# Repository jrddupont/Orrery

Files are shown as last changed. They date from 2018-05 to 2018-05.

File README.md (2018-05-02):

# Digital Orrery

This is a project to create a digital [orrery][orrery], each planet can be addressed and controlled individually.

## Parts list

* [4x Nema 17 stepper motors, 40mm][motors]
* An Arduino Uno
* [Arduino CNC shield][cnc]
* All of the 3D printed parts

## Current Functions

Currently the orrery has two functions, animate and date mode. In its default mode, the orrery slowly spins the four planets at realistic relative speeds meaning that Mars spins 8 times slower than Mercury. The accuracy of the animation is acceptable as it is within 4% of real speeds, although the method used creates unrealistic cycles that happen noticeably often.  
The second function is to snap to a position when given a date over serial. When given an input date, the number of days between the given date and 1/1/2000 is calculated. The actual positions of the planets at 1/1/2000 is known as well as how far the planets move in a day, so it is as simple as multiplying the day delta by the planet speed to find its new location. 

## Problems  

There are a number of problems with this device, namely that it slowly drifts out of alignment and becomes inaccurate. The source of this inaccuracy is from stepper motors missing steps, so a solution may be to increase power to the steppers or to measure where the planets are via a rotary encoder.   
In a similar vein, when the orrery is started it takes its current state as being zeroed out and will assume all the planets are aligned. This is undesired because it means that every single time it is started it needs to be realigned. This problem would also be fixed with rotary encoders. 

## Future Plans

Things I would like to add or fix:  
* Some way for the arduino to know where the planets are, either a rotary encoder or a bump that a switch can detect. 
* An LCD screen and buttons to allow user input without the need for a computer.
* An enclosure for the arduino and shield to make transportation easier, as well as improve aesthetics. 

## Demonstration

Whole device:  
Whole device  

Close up:  
Closer device

Video:  
Video (http://www.youtube.com/watch?v=tbyMe05wM1g "Orrery Working")

More info found [here][thingiverse]

[thingiverse]: https://www.thingiverse.com/thing:2889266
[motors]: https://www.amazon.com/gp/product/B00PNEQI7W
[cnc]: https://www.amazon.com/gp/product/B06XJKVLG3
[wide]: https://i.imgur.com/hOvwWhX.jpg 
[close]: https://i.imgur.com/2LTnKSo.jpg
[orrery]: https://en.wikipedia.org/wiki/Orrery

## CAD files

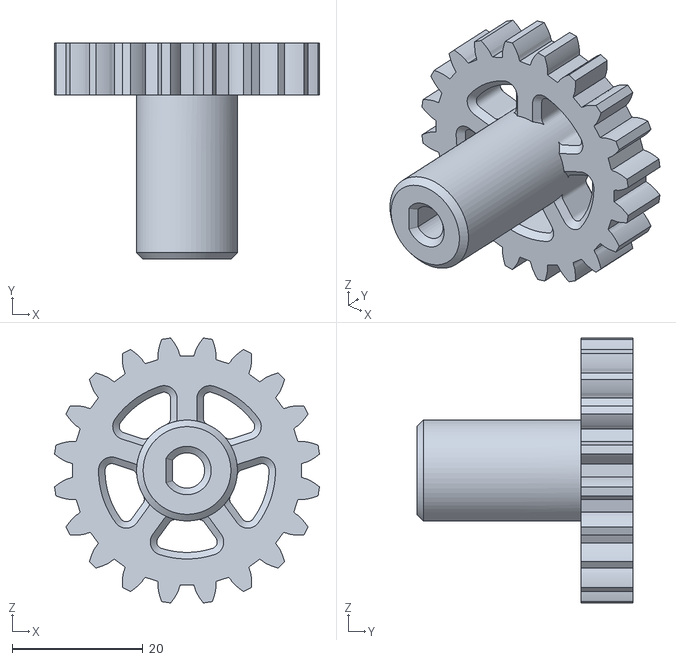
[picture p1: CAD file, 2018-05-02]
3D Parts/Drive 3.stl
40.5 x 33.1 x 40.5

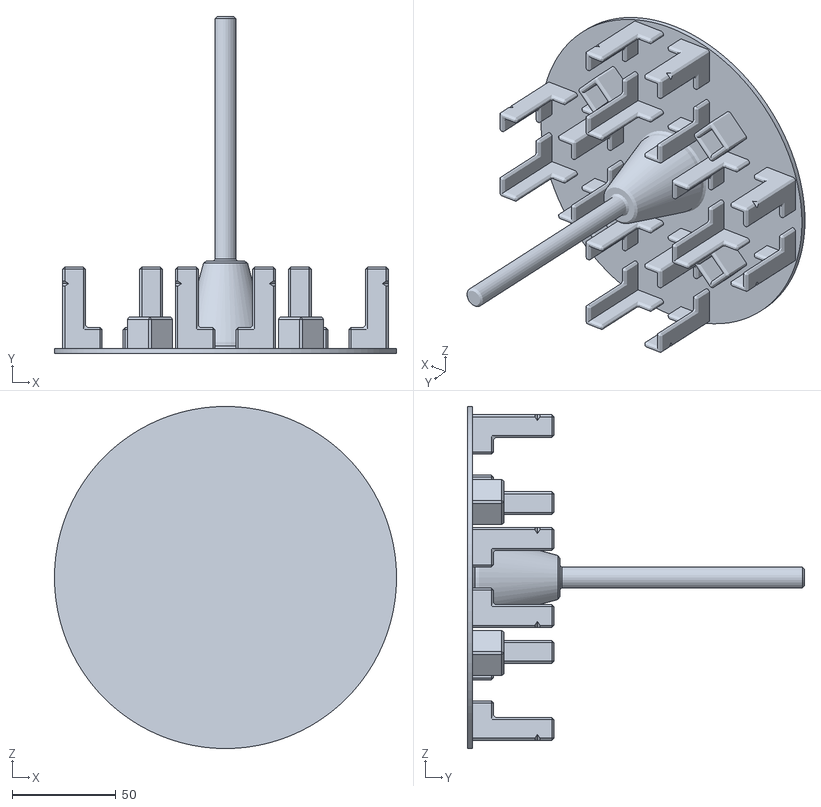
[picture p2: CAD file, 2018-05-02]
3D Parts/Base.stl
165.0 x 162.5 x 165.0

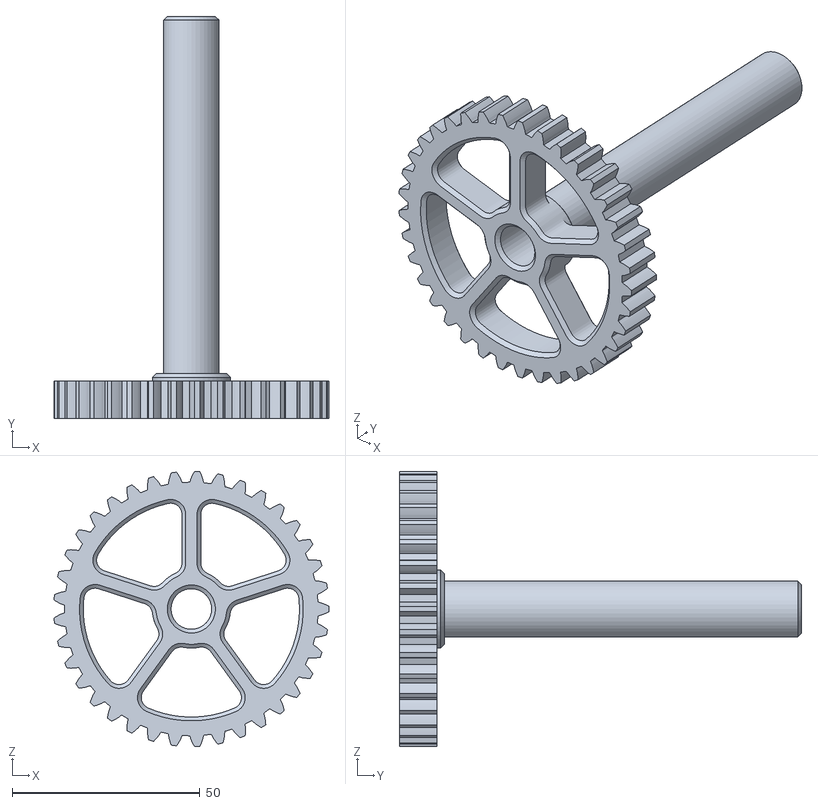
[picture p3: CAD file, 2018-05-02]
3D Parts/Shaft 1.stl
73.2 x 107.0 x 73.2

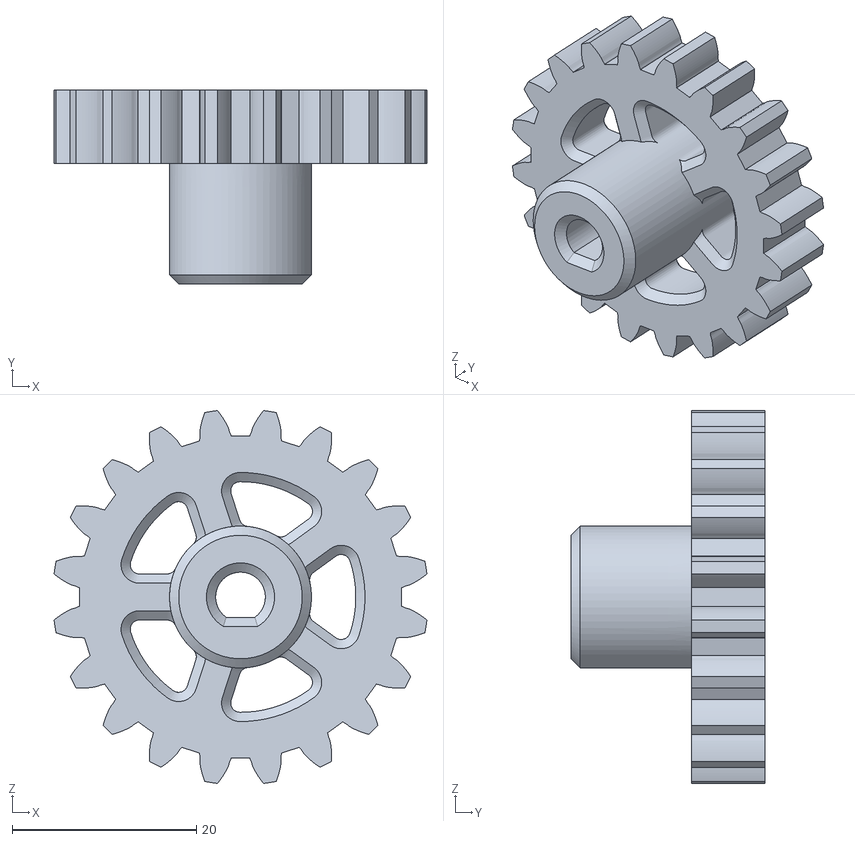
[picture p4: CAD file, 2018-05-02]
3D Parts/Drive 2.stl
40.5 x 21.1 x 40.5

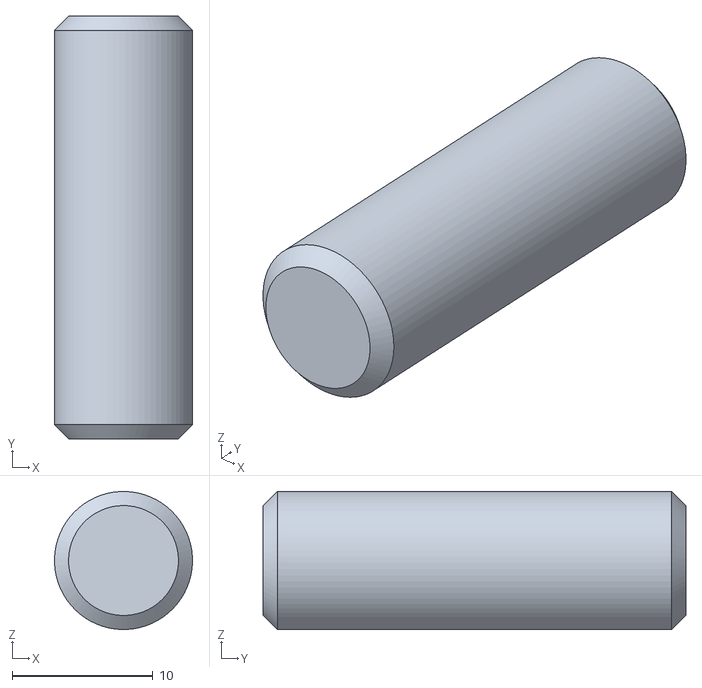
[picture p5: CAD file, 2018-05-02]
3D Parts/Sun Pin.stl
9.80 x 30.0 x 9.80

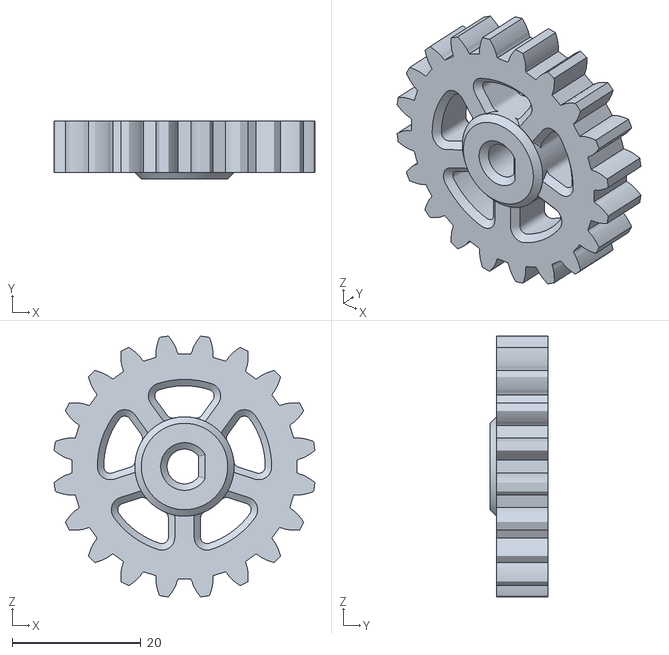
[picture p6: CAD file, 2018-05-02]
3D Parts/Drive 1.stl
40.5 x 9.05 x 40.5

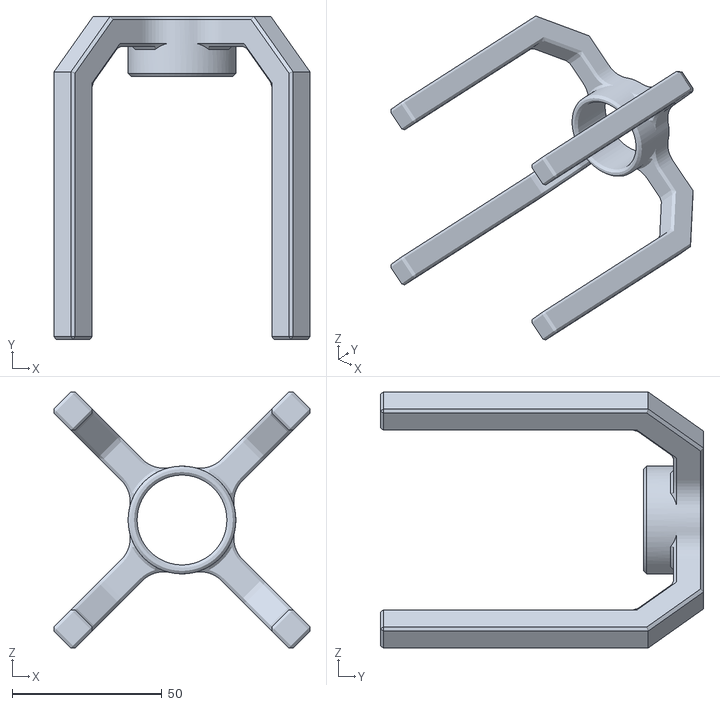
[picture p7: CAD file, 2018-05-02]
3D Parts/Support Strut.stl
85.6 x 108.0 x 85.6

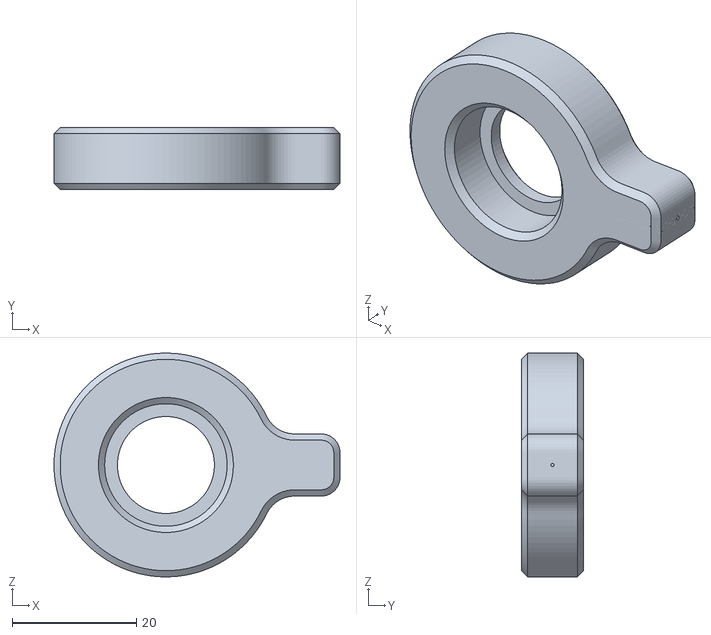
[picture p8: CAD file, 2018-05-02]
3D Parts/Collar 2.stl
46.0 x 10.0 x 36.0

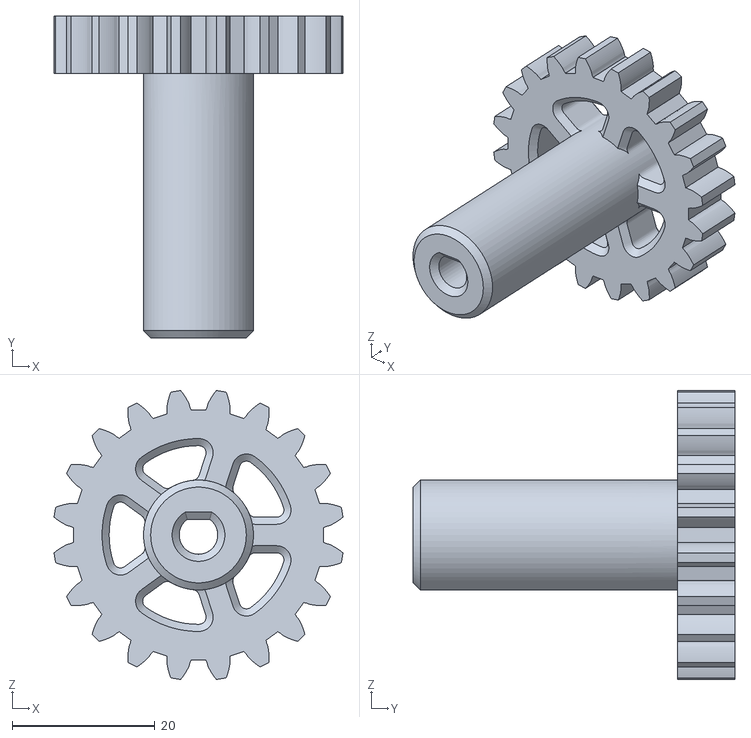
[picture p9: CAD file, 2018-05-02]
3D Parts/Drive 4.stl
40.5 x 45.1 x 40.5

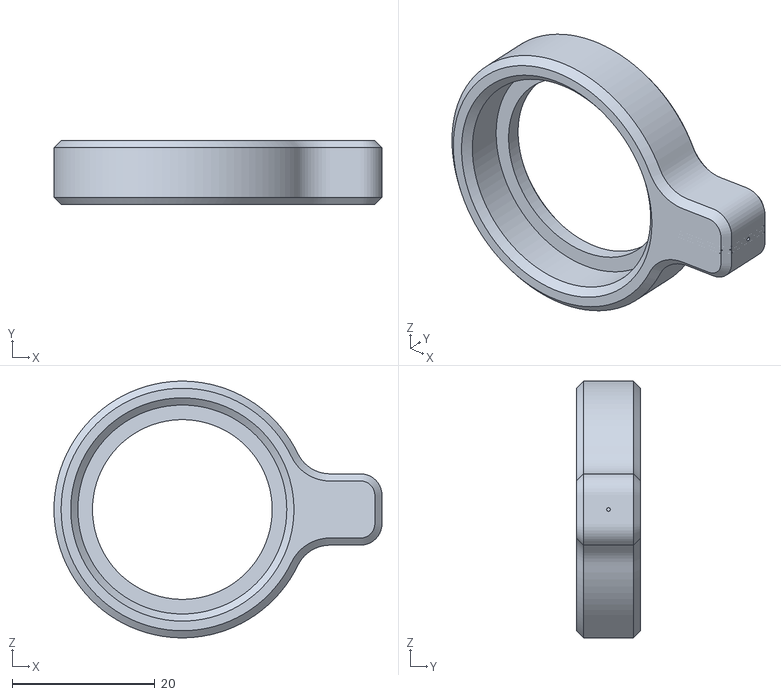
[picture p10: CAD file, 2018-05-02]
3D Parts/Collar 4.stl
46.0 x 9.00 x 36.0

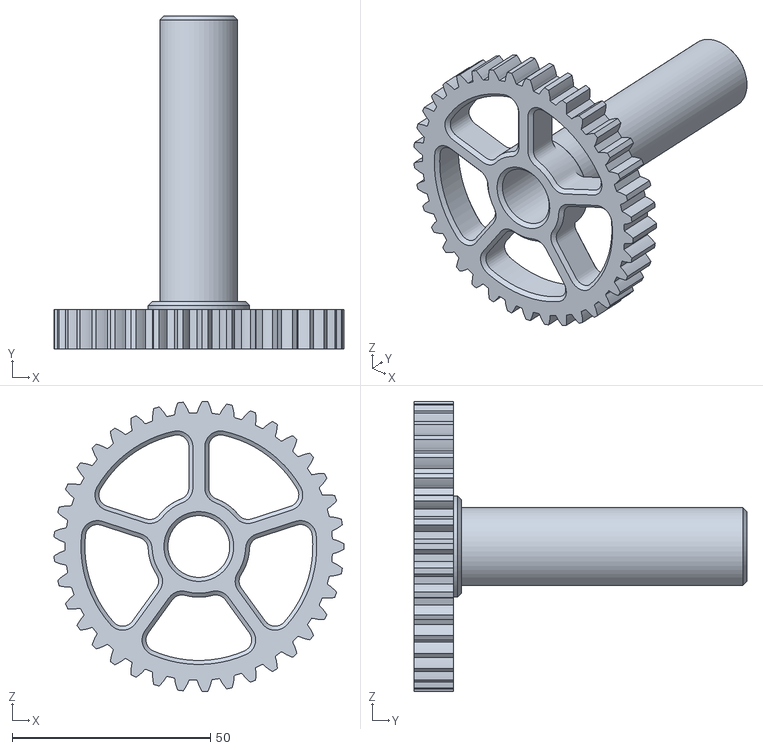
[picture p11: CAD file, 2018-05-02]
3D Parts/Shaft 2.stl
73.2 x 84.0 x 73.2

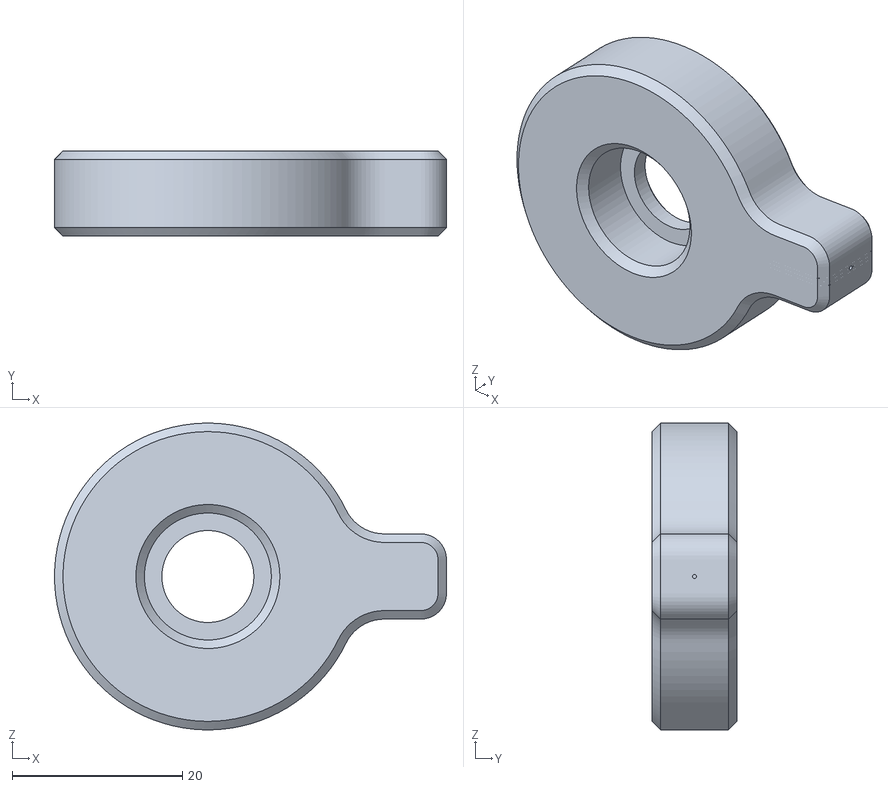
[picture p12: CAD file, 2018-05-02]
3D Parts/Collar 1.stl
46.0 x 10.0 x 36.0

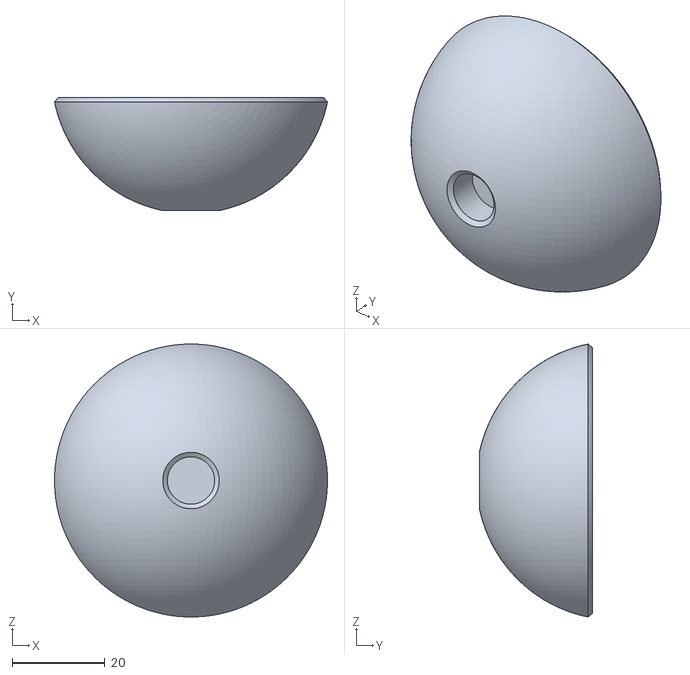
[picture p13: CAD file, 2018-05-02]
3D Parts/Sun Lower.stl
58.8 x 24.4 x 58.8

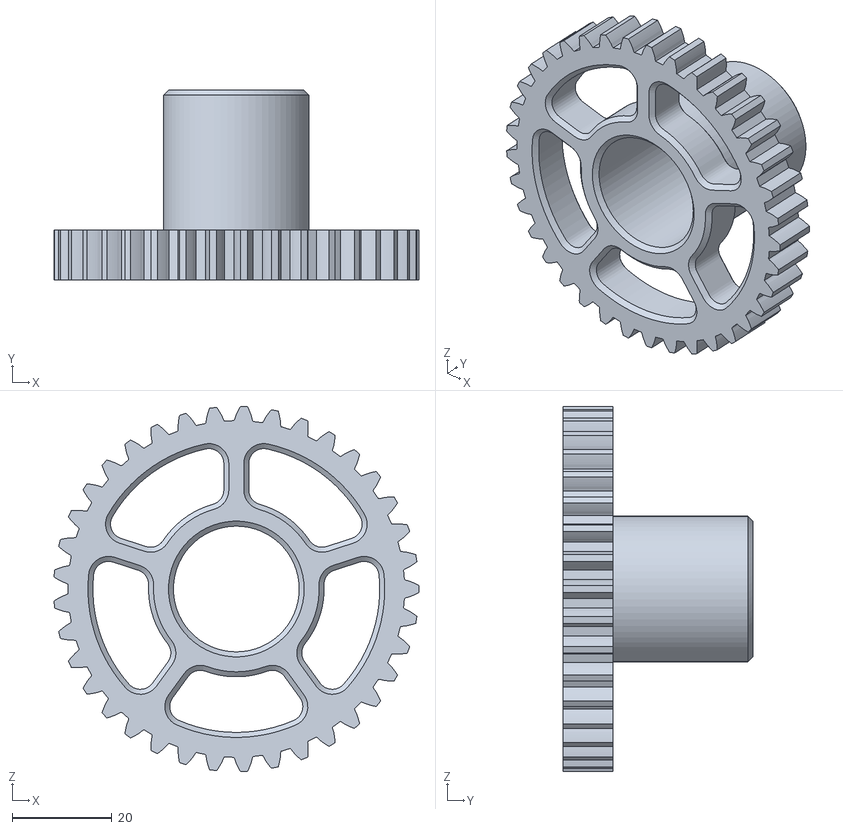
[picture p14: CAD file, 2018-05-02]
3D Parts/Shaft 4.stl
73.2 x 38.0 x 73.2

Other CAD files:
3D Parts/Collar 3.stl
3D Parts/Sun Upper.stl
3D Parts/Shaft 3.stl

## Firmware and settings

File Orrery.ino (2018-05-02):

#define MAX_STEP (2960)		// Number of steps per full planet revolution
#define STEP_DELAY (150)	// Time in uS to wait inbetween steps

#define CHECK_BIT(var,pos) ((var) & (1<<(pos)))	// Checks if bit `pos` in `var` is 1
#define TO_RADIAN(A) (PI * (A) / 180)	// Converts from degree to radian
#define TO_DEGREE(R) ((R) * (180/PI))	// Converts from radian to degree
#define POS_TO_STEP(P) (P * MAX_STEP)	// Converts a float from 0-1 to 0-MAX_STEP


#define ENABLE (8)	// Pin that enables or disables all motor control

// Direction pins
#define MRC_DIR	(5)
#define VNS_DIR	(6)
#define ERT_DIR	(13)
#define MRS_DIR	(7)

// Step pins
#define MRC_STP	(2)
#define VNS_STP	(3)
#define ERT_STP	(12)
#define MRS_STP	(4) 

// Enumerations for the planets, used primaraly as indexes for arrays
#define MERCURY (0)
#define VENUS (1)
#define EARTH (2)
#define MARS (3)

// Directions :D
#define LEFT (true)
#define RIGHT (!LEFT)

// Defines what mode to send to the arduino, currently only HYBRID exists. 
#define HYBRID

// A date has day 'd', month 'm' and year 'y'
struct Date {
	int d, m, y;
};

byte directionPins[4] = {MRC_DIR, VNS_DIR, ERT_DIR, MRS_DIR};
byte stepPins[4] = {MRC_STP, VNS_STP, ERT_STP, MRS_STP};

int stepPositions[4] = {0, 0, 0, 0};	// Current actual positons of the stepper motors, although this can become inaccurate over time with missed steps
float floatPositions[4] = {0, 0, 0, 0}; 	// Desired position to go to when stepToCurrentPosition() is called

// Variables for serial date input
Date inputDate = {.d = 0, .m = 0, .y = 0};
boolean inputComplete = false;  // whether the input is complete

void setup(){
	// Starts serial
	Serial.begin(9600);
	
	// Set all direction, step, and enable pins to output
	for(int i = 0; i < 4; i++){
		pinMode(directionPins[i], OUTPUT);
		pinMode(stepPins[i], OUTPUT);
	}
	pinMode(ENABLE, OUTPUT);

	// Setup animation
	initAnimation();
	
	// 5 second delay before starting animation to allow for manual alignment
	digitalWrite(ENABLE, HIGH);
	delay(5000);
	digitalWrite(ENABLE, LOW);
	delay(500);
}

void loop(){
	#ifdef HYBRID
		// If there is a date input
		if (inputComplete) {
  			Serial.println(inputDate.y);
  			Serial.println(inputDate.m);
  			Serial.println(inputDate.d);

  			// calculate input date's position and snap to it, then wait 5 seconds before animating again
  			setPositionByDate(inputDate);
  			stepToCurrentPosition();
  			delay(5000);
  			inputDate = {.d = 0, .m = 0, .y = 0};
  			inputComplete = false;
  			initAnimation();
		}
		animationStep();	// Just keep animating if there was no input
		delay(2);	// This can be adjusted to make it animate faster or slower
		//delayMicroseconds(1000);	// Minimum is probably like 250 
	#endif
}

// Patterns that all the planets step to while in an animation state, Mercury always steps and MARS steps 1/8 of the time, etc.
byte stepPatterns[4] = { B11111111, B10100100, B10001000, B10000000};
byte currentAnimationStep = 0; // Will always be 0-7

// Makes one animation step, DOES NOT delay at all, must delay outside of this function (calling this in a loop will cause the steppers to miss steps)
void animationStep(){

	// If the position of the current animation step has a 1, make the step
	for(int planet = 0; planet < 4; planet++){
		if(CHECK_BIT(stepPatterns[planet], currentAnimationStep)){
			stepPositions[planet] = (stepPositions[planet] + 1) % MAX_STEP;
			digitalWrite(stepPins[planet], HIGH);
		}
	}
	// Minimum amount of time for the step to successfully happen
	delayMicroseconds(STEP_DELAY);

	// Reset all pins to low
	for(int planet = 0; planet < 4; planet++){
		digitalWrite(stepPins[planet], LOW);
	}
	delayMicroseconds(STEP_DELAY);
	currentAnimationStep = (currentAnimationStep + 1) % 8;
}

// Must be called before attempting to animate
void initAnimation(){
	currentAnimationStep = 0;
	for(int planet = 0; planet < 4; planet++){
		digitalWrite(directionPins[planet], RIGHT);
	}
}

//referenceLoactions {0.491778, 0.2945, 0.0664444, 0.7875};	// Solar lon (0-1) of 01/01/2000
int referenceLoactions[4] = {4917, 2945,  664, 7875};	// Solar lon (0-10000) of 01/01/2000
float orbitalSpeeds[4] = {113.636, 44.5038, 27.3823, 14.556};	// How far a planet moves in a day
Date referenceDate = {.d = 1, .m = 1, .y = 2000};

// Sets 'floatPositions' based on an input date
void setPositionByDate(Date d){

	// Difference in days between given date and reference date
	long days = getDifference(referenceDate, d);

	// Calculate the new position of each planet 
	for(int planet = 0; planet < 4; planet++){
		long newPosition = (referenceLoactions[planet] + (long)(days * orbitalSpeeds[planet])) % 10000;	
		floatPositions[planet] = newPosition / 10000.0;
	}
}

// Calculate how to step to floatPositions, then step there
void stepToCurrentPosition() {

	// Calculate step sequence and direction
	currentAnimationStep = 0;
	int steps[4] = {0, 0, 0, 0};
	boolean dir[4] = {false, false, false, false};

	for(int planet = 0; planet < 4; planet++){
		int current_step = stepPositions[planet];
		int target_step = POS_TO_STEP(floatPositions[planet]);
		int distance_r, distance_l;
		// these formulas can probably be reduced
		if(target_step == current_step) {	// no need to move
			continue;
		} else if(target_step < current_step) {
			distance_r = (MAX_STEP - current_step) + target_step;
			distance_l = current_step - target_step;
		} else {
			distance_r = target_step - current_step;
			distance_l = current_step + (MAX_STEP - target_step);
		}
		// call step function in correct direction
		//dir[planet] = distance_l < distance_r;	// Find shortest direction
		dir[planet] = distance_l > distance_r;	// Find longer direction
		steps[planet] = (dir[planet] ? distance_l : distance_r);
	}

	// Move the motors
	int maxStep = -1;
	for(int planet = 0; planet < 4; planet++){
		if(steps[planet] > maxStep){
			maxStep = steps[planet];
		}
		digitalWrite(directionPins[planet], dir[planet]);
		stepPositions[planet] +=  dir[planet] ? -steps[planet] : steps[planet];
		if(stepPositions[planet] < 0){
			stepPositions[planet] = stepPositions[planet] + MAX_STEP;
		}
		stepPositions[planet] %= MAX_STEP;
	}
	
	for(int i = 0; i < maxStep; ++i) {
		for(int planet = 0; planet < 4; planet++){
			if(i < steps[planet]){
				digitalWrite(stepPins[planet], HIGH); 
			}
		}
		delayMicroseconds(STEP_DELAY); 
		for(int planet = 0; planet < 4; planet++){
			if(i < steps[planet]){
				digitalWrite(stepPins[planet], LOW); 
			}
		}
		delayMicroseconds(STEP_DELAY); 
		delay(1);
	}
	
}


// Event to capture date input
void serialEvent() {
	// Date should be input as "YYYY MM DD" or for example "2000 1 1". It is important that there is a newline 
	int inputYear = Serial.parseInt();
	int inputMonth = Serial.parseInt();
	int inputDay = Serial.parseInt();

	// Stick it into the date object
	inputDate = {.d = inputDay, .m = inputMonth, .y = inputYear};

	// Eat any remaining input
	while (Serial.available()) {
		if ((char)Serial.read() == '\n') {
			inputComplete = true;
		}
	}
}


// Date math found here: https://www.geeksforgeeks.org/find-number-of-days-between-two-given-dates/ 
// I'm trusting that it works
const int monthDays[12] = {31, 28, 31, 30, 31, 30, 31, 31, 30, 31, 30, 31}; 
// This function counts number of leap years before the given date
int countLeapYears(Date d) {
	int years = d.y;
	// Check if the current year needs to be considered
	// for the count of leap years or not
	if (d.m <= 2){
		years--;
	}
	// An year is a leap year if it is a multiple of 4,
	// multiple of 400 and not a multiple of 100.
	return years / 4 - years / 100 + years / 400;
}
 
// This function returns number of days between two given dates
int getDifference(Date dt1, Date dt2) {
	// COUNT TOTAL NUMBER OF DAYS BEFORE FIRST DATE 'dt1'
	// initialize count using years and day
	long int n1 = dt1.y*365 + dt1.d;
	// Add days for months in given date
	for (int i=0; i<dt1.m - 1; i++){
		n1 += monthDays[i];
	}
	// Since every leap year is of 366 days,
	// Add a day for every leap year
	n1 += countLeapYears(dt1);
 
	// SIMILARLY, COUNT TOTAL NUMBER OF DAYS BEFORE 'dt2'
	long int n2 = dt2.y*365 + dt2.d;
	for (int i=0; i<dt2.m - 1; i++){
		n2 += monthDays[i];
	}
	n2 += countLeapYears(dt2);
	// return difference between two counts
	return (n2 - n1);
}

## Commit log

2018-05-02 Added 3D parts as well as fusion 360 parts
    [Base.stl, Collar 1.stl, Collar 2.stl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]
2018-05-02 Replaced spaces with tabs
    [Orrery.ino]
